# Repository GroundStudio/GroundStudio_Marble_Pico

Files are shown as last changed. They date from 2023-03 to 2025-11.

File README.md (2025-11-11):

GroundStudio Marble Pico
====================================
Marble Pico REV0 0 3

Get it from:

[digikey.com](https://www.digikey.com/en/products/detail/groundstudio/RLJDMV-AAA/21080805)

[ardushop.ro](https://ardushop.ro/en/groundstudio/1590-marble-pico-6427854000682.html)

Explore all the GroundStudio products at [ardushop.ro](https://ardushop.ro/en/37-groundstudio)

Description
-------------------
RP2040 based development board with 26 GPIO, 16 controllable PWM channels, three 12-bit ADC with dedicated ADC voltage reference, 8MB external SPI Flash memory, I²C 3V3 adapter and microSD card adapter.

Contents
-------------------

* [/Documentation](https://github.com/GroundStudio/GroundStudio_Marble_Pico/tree/main/Documentation) -- Contains documentation written during creation of this repository, with readme.md index of its own!
* [/Firmware](https://github.com/GroundStudio/GroundStudio_Marble_Pico/tree/main/Firmware) -- Firmware (bootloaders, etc)
* [/Hardware](https://github.com/GroundStudio/GroundStudio_Marble_Pico/tree/main/Hardware) -- Schematics, layout.
* [/Libraries](https://github.com/GroundStudio/GroundStudio_Marble_Pico/tree/main/Libraries) -- Arduino/CircuitPython libraries. 

Versions
-------------------
*(Not all tags shown)*
* [V0.0.3] Initial release version

License
-------------------
This is released under the [Attribution-ShareAlike 4.0 International (CC BY-SA 4.0)](https://creativecommons.org/licenses/by-sa/4.0/) license. 
**You are welcome to use this for commercial purposes.**

Please consider contributing back to this project or others to help the open-source hardware community continue to thrive and grow! 

Certifications:   
[Open Source Hardware Association](https://certification.oshwa.org/ro000001.html)  
   
certification-mark-RO000001-wide (https://certification.oshwa.org/ro000001.html)

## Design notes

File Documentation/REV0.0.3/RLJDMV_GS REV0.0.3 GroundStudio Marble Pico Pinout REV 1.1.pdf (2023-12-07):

# GroundStudio Marble Pico

RP2040 based development board with 25 GPIO, 16 controllable PWM channels, three 12-bit ADC with dedicated ADC voltage reference, 8MB external SPI Flash memory, I²C 3V3 adapter and microSD card adapter

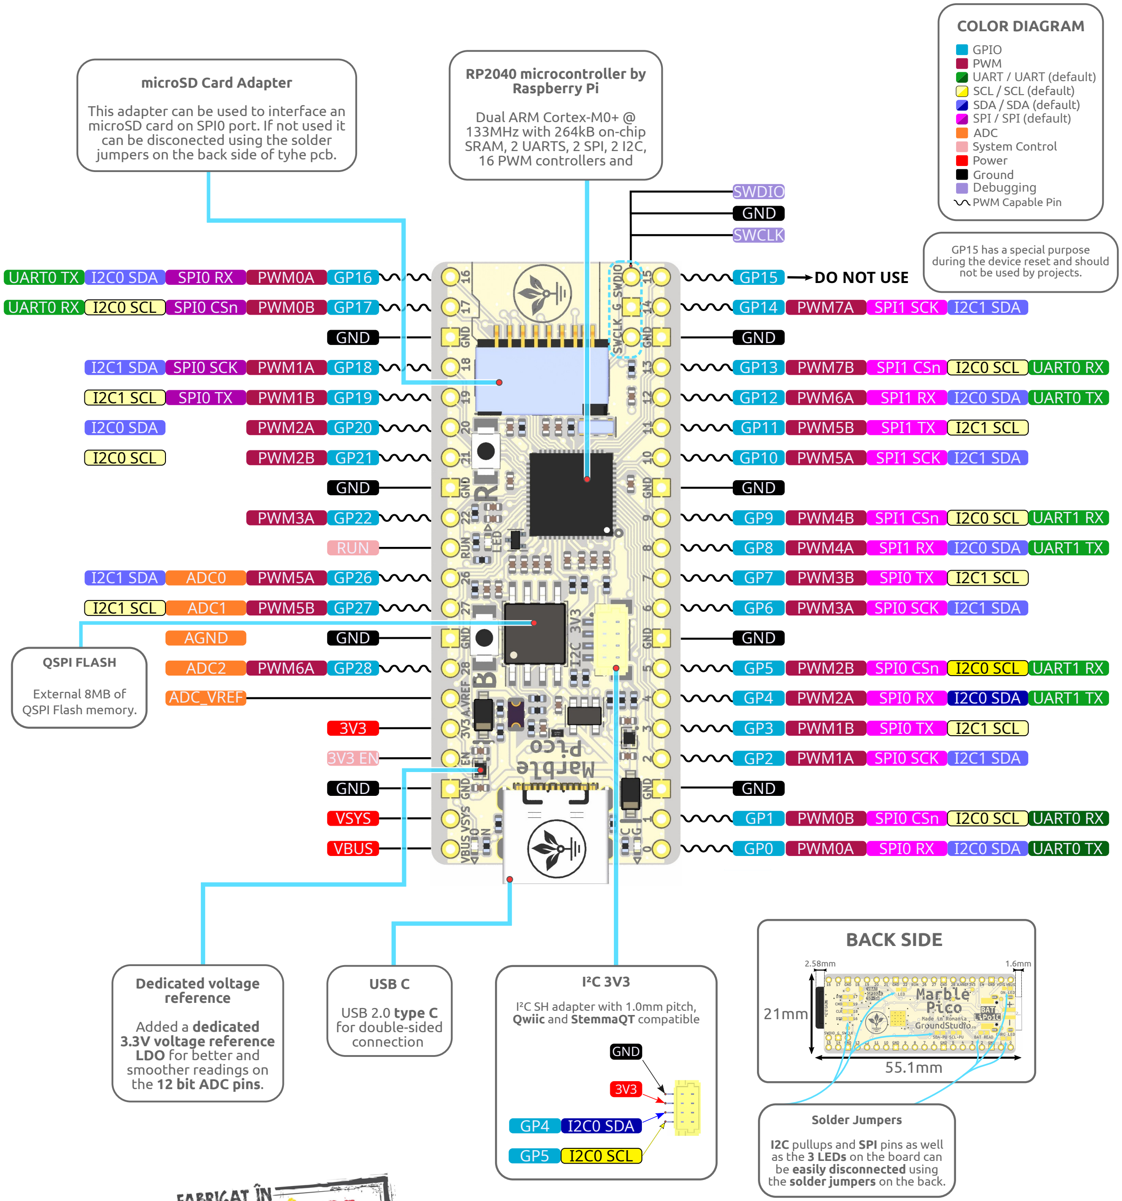
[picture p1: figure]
ADC_VREF; AGND ADC2; ADC0 ADC1; SPI0 RX PWM0A SPI0 CSn; SPI0 SCK SPI0 TX; I2C0 SDA I2C0 SCL; I2C1 SDA I2C1 SCL I2C0 SDA I2C0 SCL; I2C1 SDA I2C1 SCL; UART0 RX; UART0 TX; PWM0B; PWM1A PWM1B PWM2A PWM2B; PWM7B PWM6A PWM5B PWM5A; PWM4B PWM4A PWM3B PWM3A; PWM2B PWM2A PWM1B PWM1A; PWM3A; PWM5A PWM5B; PWM6A; PWM7A; PWM0B PWM0A; GND; RUN; SWCLK; SWDIO; VBUS; VSYS; UART0 RX UART0 TX; UART1 RX UART1 TX; SPI1 RX; SPI0 CSn; SPI0 SCK; SPI0 TX; SPI0 RX; SPI1 CSn; SPI1 SCK; SPI1 TX; I2C0 SDA; I2C0 SCL; I2C1 SDA; I2C1 SCL; RP2040 microcontroller by Raspberry Pi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

This adapter can be used to interface an microSD card on SPI0 port. If not used it

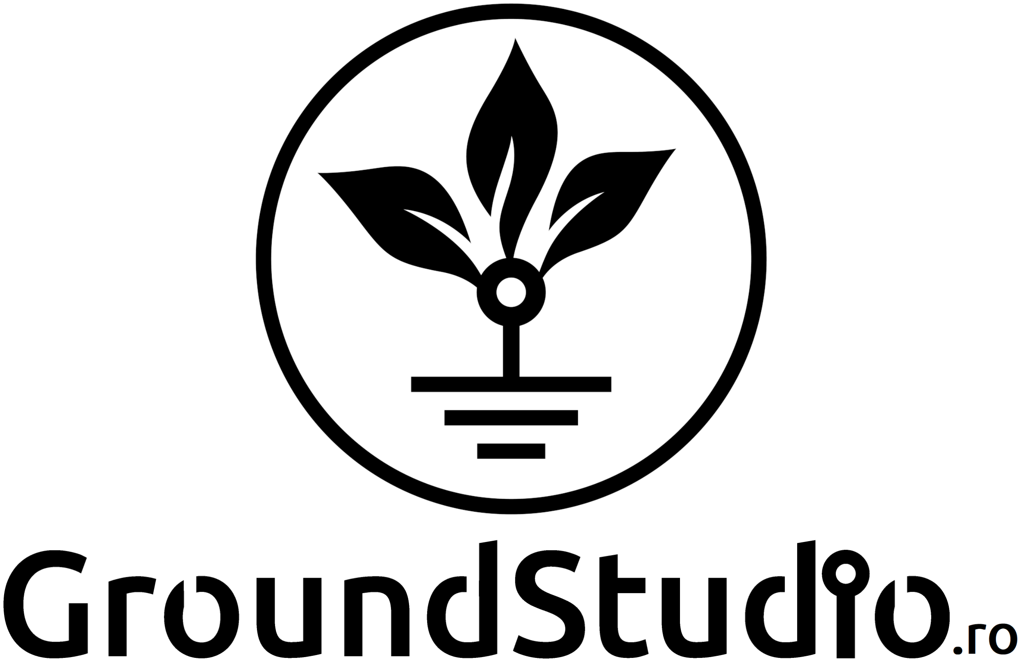
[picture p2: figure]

Board:

Credits:

Copyright:

License:

ARDUSHOP SRL 2023

Attribution-ShareAlike 4.0 International

CC BY-SA 4.0 | Pinout REV: 1.1

"GroundStudio Marble Pico" RLJDMV_GS REV0.0.3

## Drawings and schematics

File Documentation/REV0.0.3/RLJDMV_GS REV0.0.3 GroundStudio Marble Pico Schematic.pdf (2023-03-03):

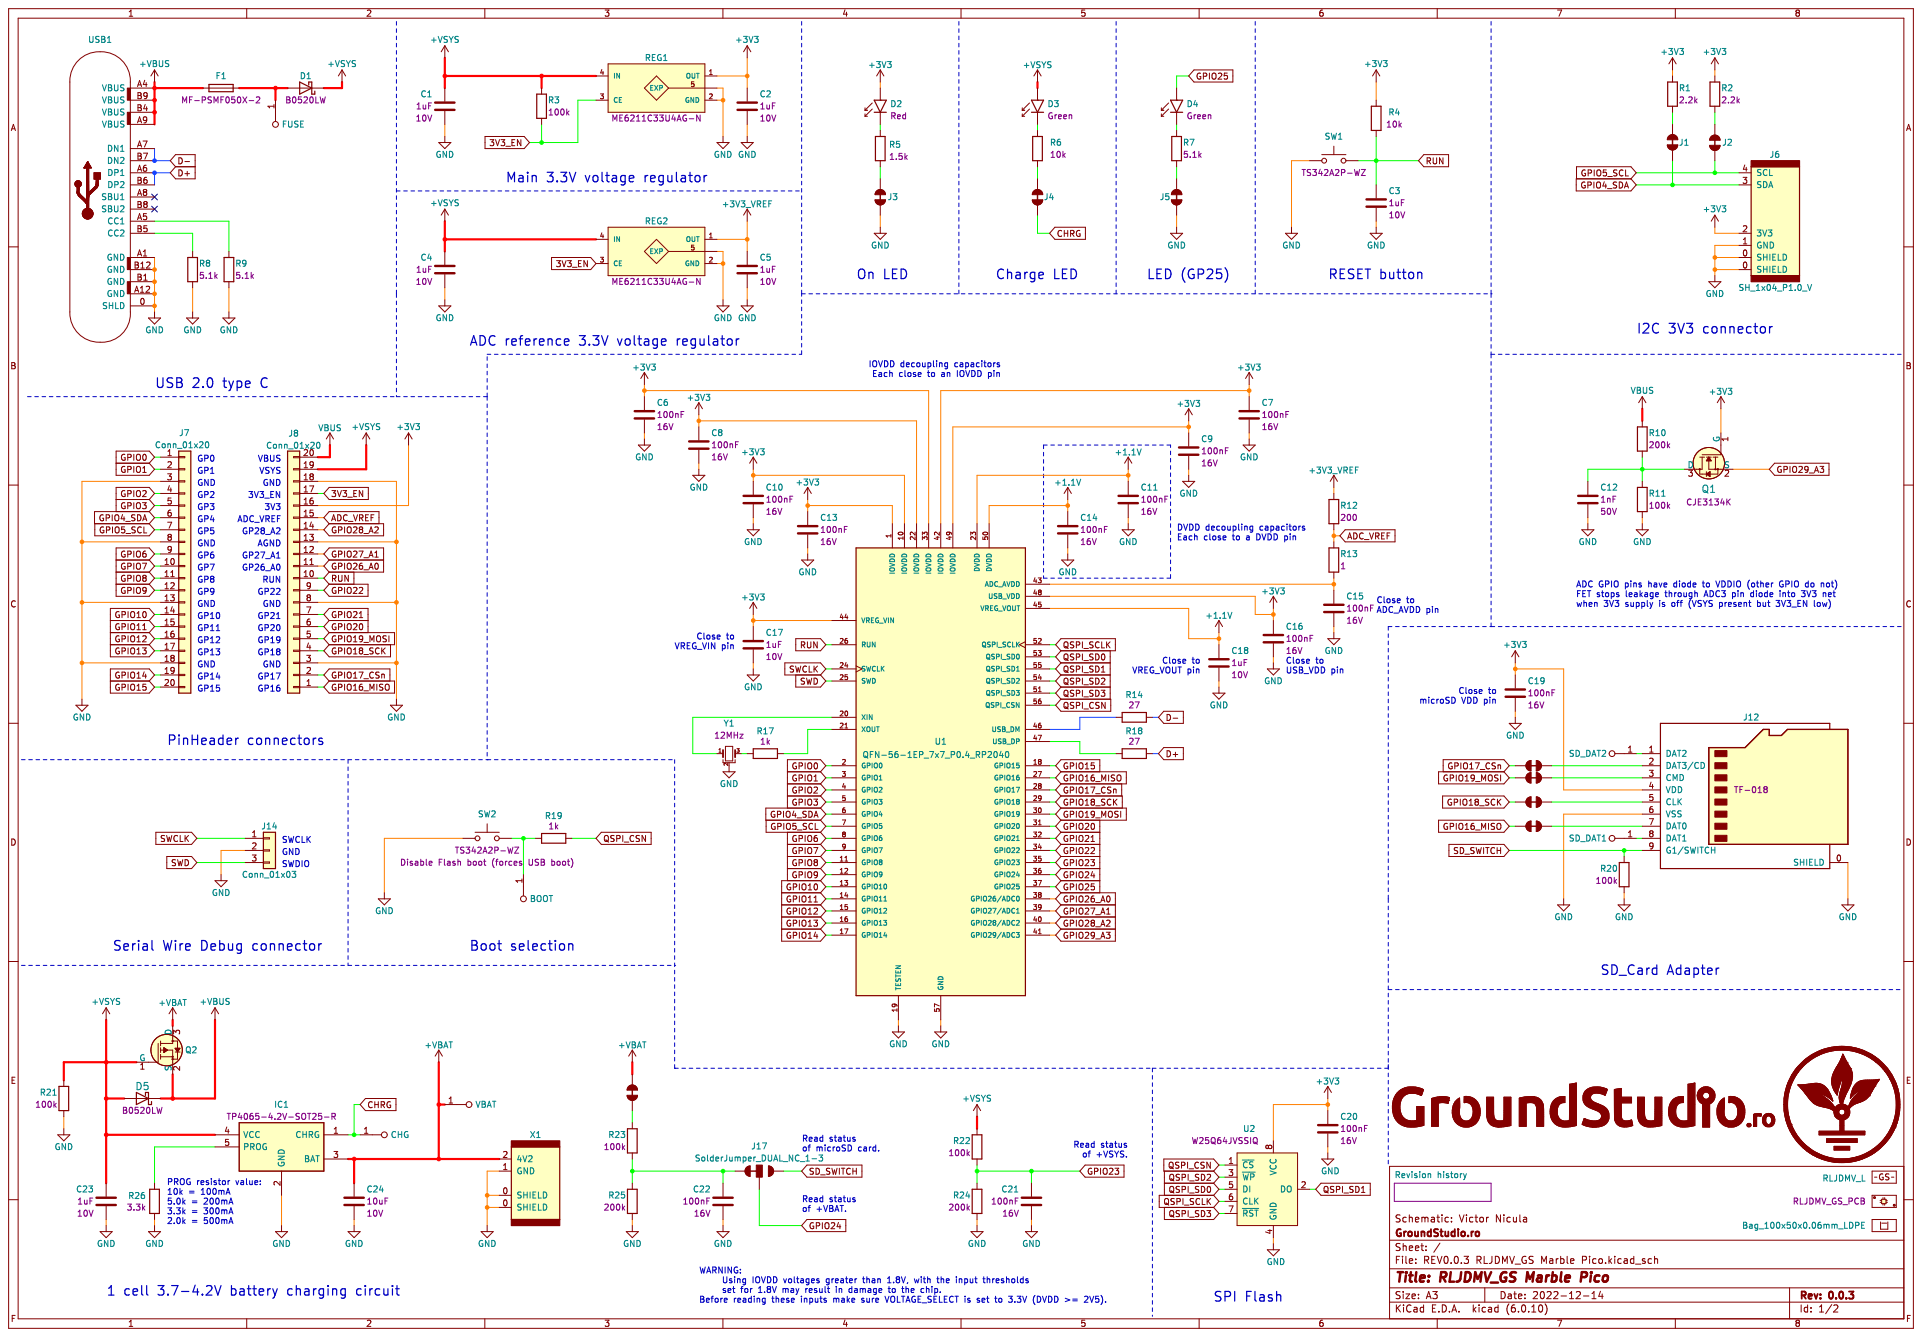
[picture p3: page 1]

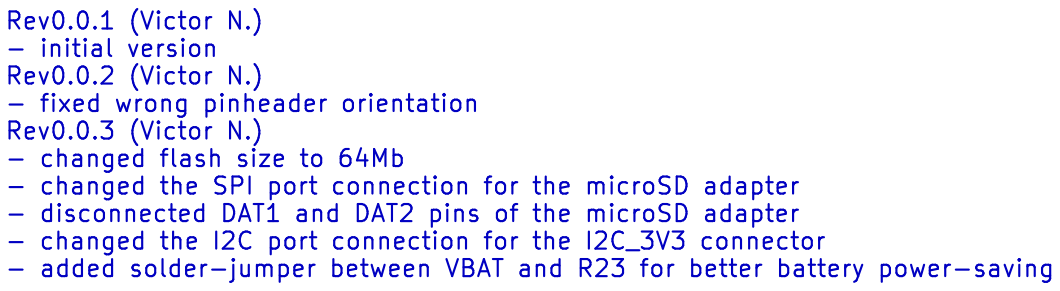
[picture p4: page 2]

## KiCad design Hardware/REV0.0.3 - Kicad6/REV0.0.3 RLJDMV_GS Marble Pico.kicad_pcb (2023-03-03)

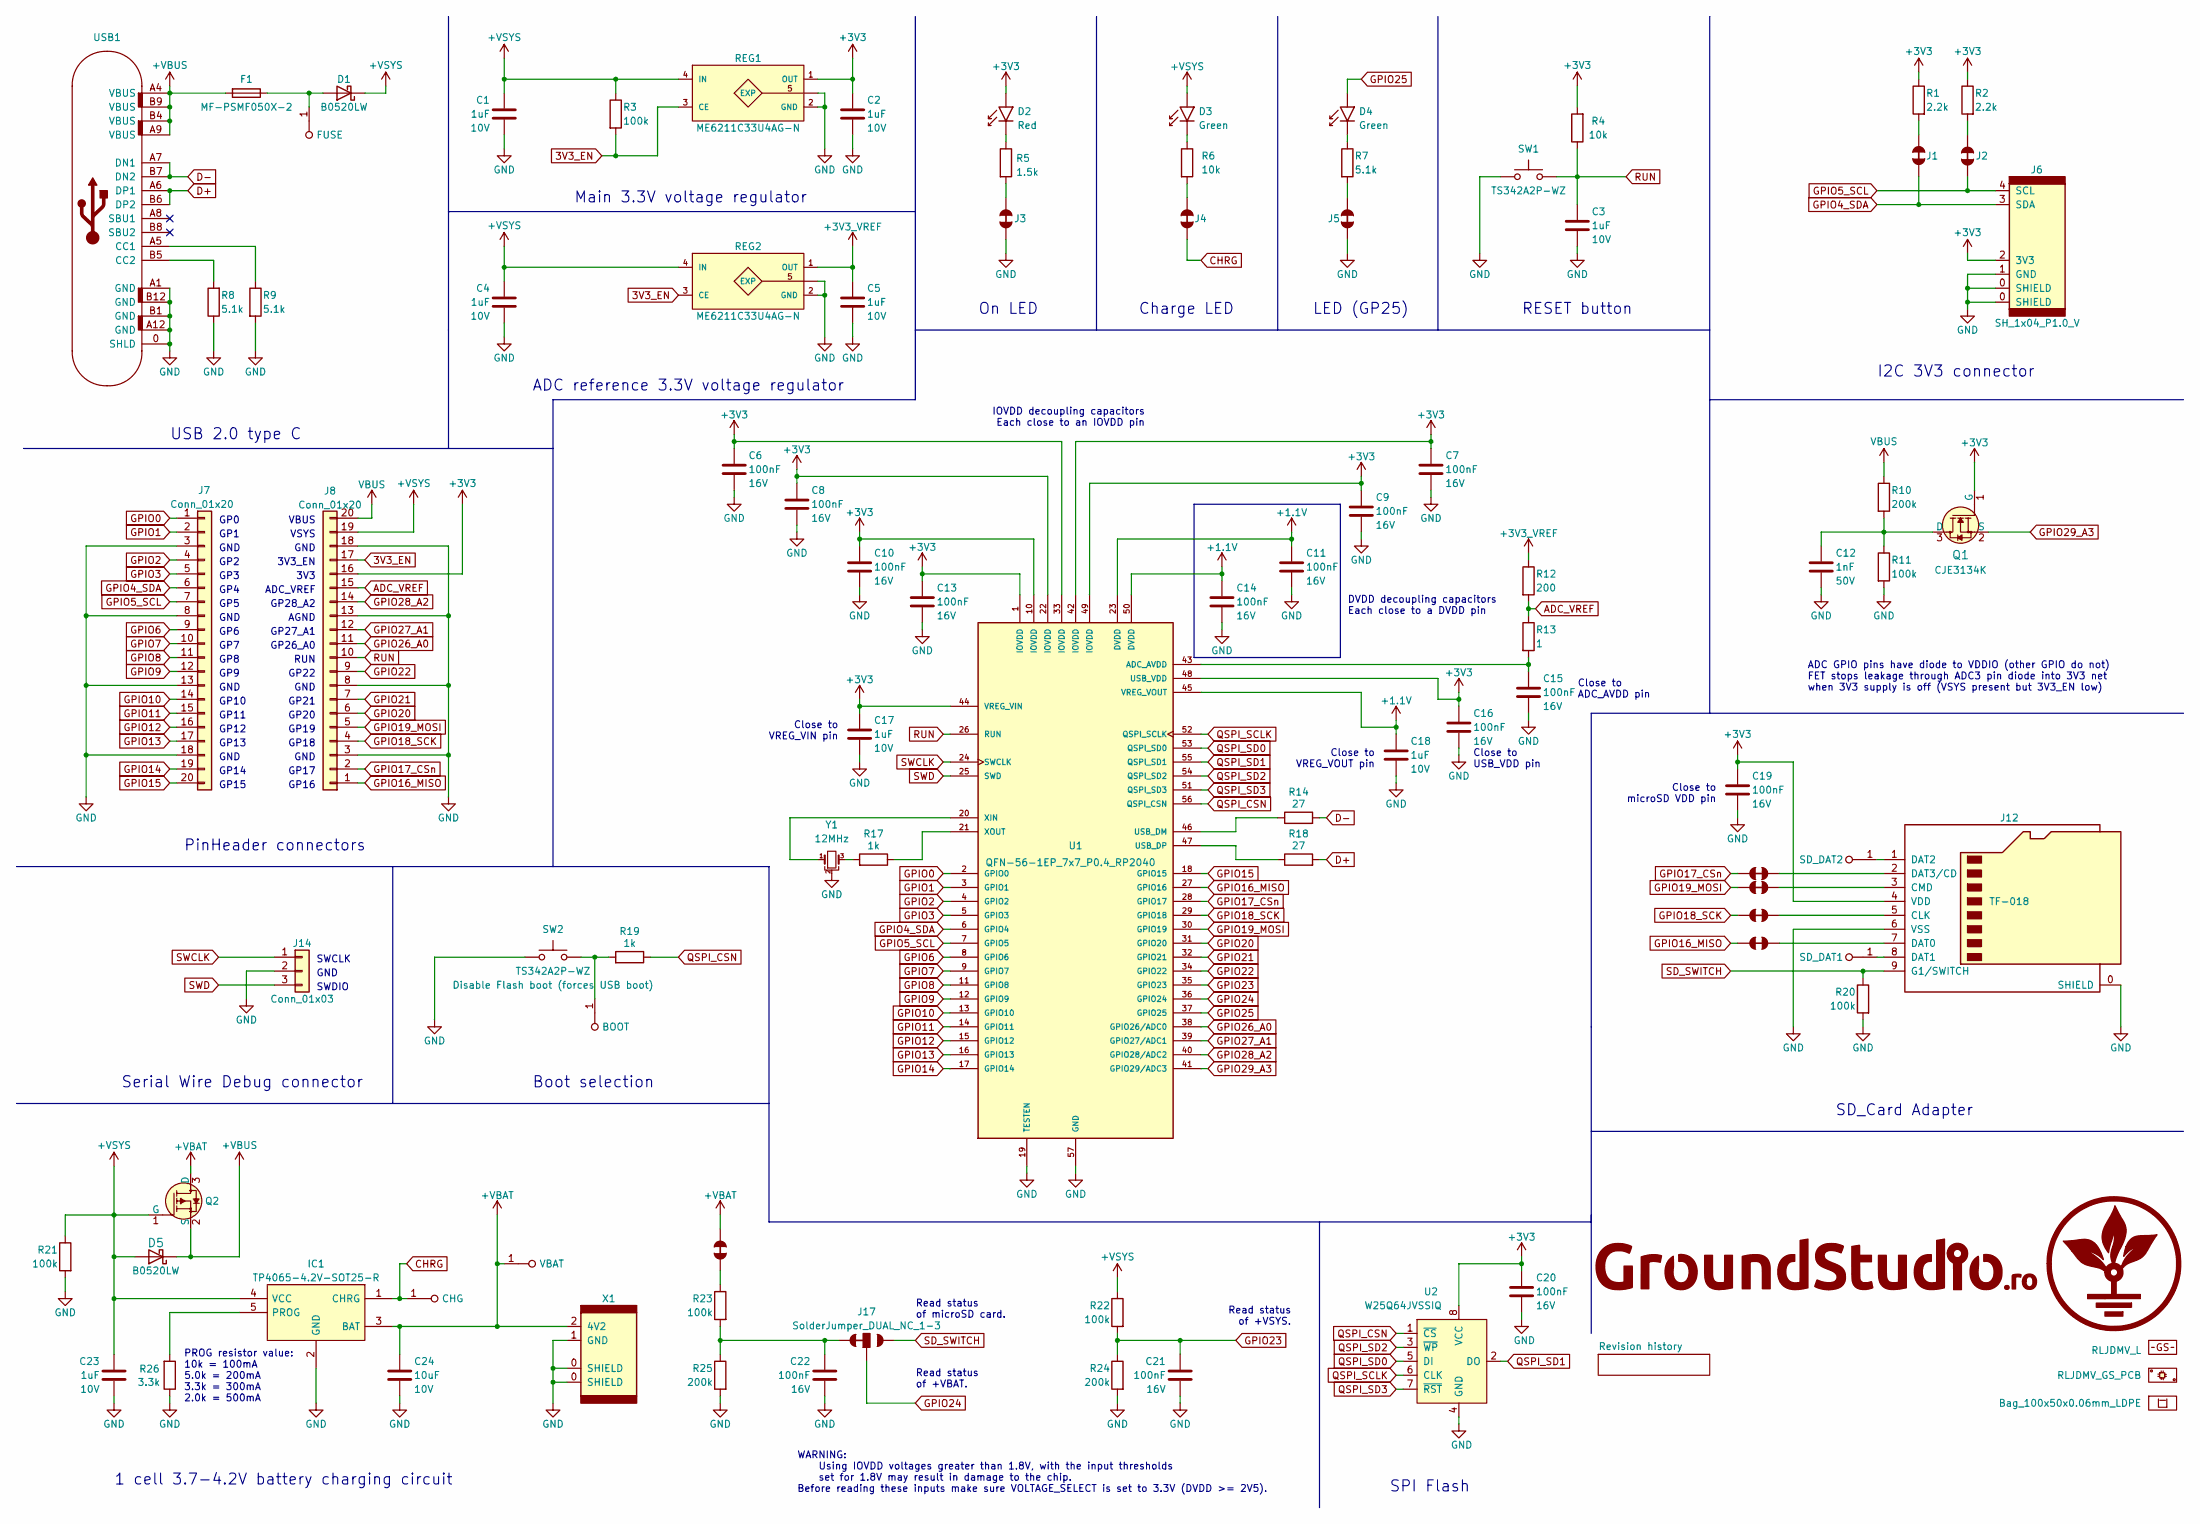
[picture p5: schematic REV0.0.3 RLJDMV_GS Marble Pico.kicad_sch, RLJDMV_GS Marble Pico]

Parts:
B1: Bag_100x50x0.06mm_LDPE; MPN KFHHEG_B
C1, C2, C3, C4, C5, C17, C18, C23: C_0402_1uF_10V; C_0402_alt; Rated voltage 10V; MPN FS15B105K100PKG; LCSC C525324
C6, C7, C8, C9, C10, C11, C13, C14, C15, C16, C19, C20, C21, C22: C_0402_100nF_16V; C_0402_alt; Rated voltage 16V; MPN 0402B104K160CT; LCSC C83056
C12: C_0402_1nF_50V; C_0402_alt; Rated voltage 50V; MPN CC0402KRX7R9BB102; LCSC C106205
C24: C_0402_10uF_10V; C_0402_alt; Rated voltage 10V; MPN LDK105CBJ106MVLF; LCSC C386033
D1, D5: SOD-123_B0520LW; SOD-123; MPN B0520LW; LCSC C89640
D2: LED_0402_RED; LED_0402_alt; MPN TZ-P2-0402RTIA1-0.45T; LCSC C779449
D3, D4: LED_0402_GREEN; LED_0402_alt; MPN TZ-P2-0402GTIA1-0.45T; LCSC C688877
F1: Fuse_0805_MF-PSMF050X-2; Fuse_0805; MPN MF-PSMF050X-2; LCSC C116170
IC1: SOT23-5_TP4065-4.2V; SOT-23-5; MPN TP4065-4.2V-SOT25-R; LCSC C113540
J1, J2, J3, J4, J5, J10, J11, J13, J15: SolderJumper_NC
J6: SH_1x04_P1.0_V; SH__1x04_P1.00mm_Vertical; MPN C145961; LCSC C145961
J7, J8: Conn_01x20; PinHeader_1x20_P2.54mm_Vertical_Male; MPN B-2100S20P-A110; LCSC C124374
J12: TF-018_microSD; TF-018; MPN TF-018; LCSC C961679
J14: Conn_01x03; PinHeader_1x03_P2.54mm_Vertical_Male; MPN C49257; LCSC C49257
J17: SolderJumper_DUAL_NC_1-3
J100: SolderJumper_NC; SolderJumper_NC_Default
L1: RLJDMV_L; MPN RLJDMV_L
P1: PCB; MPN RLJDMV_GS_PCB
Q1: SOT-523_CJE3134K; SOT-523; MPN CJE3134K; LCSC C504104
Q2: SOT-883 LP0404N3T5G; SOT-883; MPN LP0404N3T5G; LCSC C172433
R1, R2: R_0402_2.2k; R_0402_alt; MPN RC-02W2201FT; LCSC C258093
R3, R11, R20, R21, R22, R23: R_0402_100k; R_0402_alt; MPN 0402WGF1003TCE; LCSC C25741
R4, R6: R_0402_10k; R_0402_alt; MPN 0402WGJ0103TCE; LCSC C25531
R5: R_0402_1.5k; R_0402_alt; MPN 0402WGF1501TCE; LCSC C25867
R7, R8, R9: R_0402_5.1k; R_0402_alt; MPN RC-02W5101FT; LCSC C294638
R10, R24, R25: R_0402_200k; R_0402_alt; MPN 0402WGF2003TCE; LCSC C25764
R12: R_0402_200; R_0402_alt; MPN HPCR0402F200RK9; LCSC C364967
R13: R_0402_1; R_0402_alt; MPN RC-02U1R00FT; LCSC C140193
R14, R18: R_0402_27; R_0402_alt; MPN 0402WGF270JTCE; LCSC C25100
R17, R19: R_0402_1k; R_0402_alt; MPN RC-02W1001FT; LCSC C226166
R26: R_0402_3.3k; R_0402_alt; MPN RC-02W3301FT; LCSC C310224
REG1, REG2: FBP1-1-4_ME6211C33U4AG-N; FBP1-1-4; MPN ME6211C33U4AG-N; LCSC C428904
SW1, SW2: TS342A2P-WZ; MPN TS342A2P-WZ; LCSC C557591
TP1: FUSE; TestPoint
TP2: BOOT; TestPoint
TP3: CHG; TestPoint
TP4: VBAT; TestPoint
TP100: SD_DAT2; TestPoint
TP101: SD_DAT1; TestPoint
U1: QFN-56-1EP_7x7_P0.4_RP2040; QFN-56-1EP_7x7mm_P0.4mm_EP4x4mm; MPN RP2040; LCSC C2040
U2: SOIC-8_5.275x5.275_W25Q64JV; SOIC-8_5.275x5.275mm_P1.27mm; MPN W25Q64JVSSIQ; LCSC C83140
USB1: USB_C_FULL; USB_C_C167321; MPN 918-418K2023S40001; LCSC C167321
X1: PH__1x02_P2.0_H; PH__1x02_P2.00mm_Horizontal; MPN C47647; LCSC C47647
Y1: RSN_3P_3.2x1.3_CSTNE12; Rsn_muRata_CSTxE-3Pin_3.2x1.3mm; MPN CSTNE12M0G550000R0; LCSC C341520

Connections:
3V3_EN: J8.17, R3.2, REG1.3 (CE), REG2.3 (CE)
+1.1V: C11.1, C14.1, C18.1, U1.23 (DVDD), U1.45 (VREG_VOUT), U1.50 (DVDD)
+3V3: C2.1, C6.1, C7.1, C8.1, C9.1, C10.1, C13.1, C16.1, C17.1, C19.1, C20.1, D2.2 (A), J6.2 (3V3), J8.16, J12.4 (VDD), Q1.1 (G), R1.1, R2.1, R4.2, REG1.1 (OUT), U1.1 (IOVDD), U1.10 (IOVDD), U1.22 (IOVDD), U1.33 (IOVDD), U1.42 (IOVDD), U1.44 (VREG_VIN), U1.48 (USB_VDD), U1.49 (IOVDD), U2.8 (VCC)
+3V3_VREF: C5.1, R12.1, REG2.1 (OUT)
+VBAT: C24.1, IC1.3 (BAT), J100.2, Q2.3 (D), TP4.1, X1.2 (4V2)
+VSYS: C1.2, C4.2, C23.1, D1.1 (K), D3.2 (A), D5.2 (A), IC1.4 (VCC), J8.19, Q2.1 (G), R3.1, R21.1, R22.1, REG1.4 (IN), REG2.4 (IN)
ADC_VREF: J8.15, R12.2, R13.1
CHRG: IC1.1 (CHRG), J4.1, TP3.1
D+: R18.2, USB1.A6 (DP1), USB1.B6 (DP2)
D-: R14.2, USB1.A7 (DN1), USB1.B7 (DN2)
GND: C1.1, C2.2, C3.2, C4.1, C5.2, C6.2, C7.2, C8.2, C9.2, C10.2, C11.2, C12.2, C13.2, C14.2, C15.2, C16.2, C17.2, C18.2, C19.2, C20.2, C21.2, C22.2, C23.2, C24.2, IC1.2 (GND), J3.1, J5.1, J6.0 (SHIELD), J6.1 (GND), J7.3, J7.8, J7.13, J7.18, J8.3, J8.8, J8.13, J8.18, J12.0 (SHIELD), J12.6 (VSS), J14.2, R8.1, R9.2, R11.2, R20.2, R21.2, R24.2, R25.2, R26.1, REG1.2 (GND), REG1.5 (EXP), REG2.2 (GND), REG2.5 (EXP), SW1.1, SW2.1, U1.19 (TESTEN), U1.57 (GND), U2.4 (GND), USB1.0 (SHLD), USB1.A1 (GND), USB1.A12 (GND), USB1.B1 (GND), USB1.B12 (GND), X1.0 (SHIELD), X1.1 (GND), Y1.2
GPIO0: J7.1, U1.2 (GPIO0)
GPIO1: J7.2, U1.3 (GPIO1)
GPIO2: J7.4, U1.4 (GPIO2)
GPIO3: J7.5, U1.5 (GPIO3)
GPIO4_SDA: J1.2, J6.3 (SDA), J7.6, U1.6 (GPIO4)
GPIO5_SCL: J2.1, J6.4 (SCL), J7.7, U1.7 (GPIO5)
GPIO6: J7.9, U1.8 (GPIO6)
GPIO7: J7.10, U1.9 (GPIO7)
GPIO8: J7.11, U1.11 (GPIO8)
GPIO9: J7.12, U1.12 (GPIO9)
GPIO10: J7.14, U1.13 (GPIO10)
GPIO11: J7.15, U1.14 (GPIO11)
GPIO12: J7.16, U1.15 (GPIO12)
GPIO13: J7.17, U1.16 (GPIO13)
GPIO14: J7.19, U1.17 (GPIO14)
GPIO15: J7.20, U1.18 (GPIO15)
GPIO16_MISO: J8.1, J15.2, U1.27 (GPIO16)
GPIO17_CSn: J8.2, J10.2, U1.28 (GPIO17)
GPIO18_SCK: J8.4, J13.2, U1.29 (GPIO18)
GPIO19_MOSI: J8.5, J11.2, U1.30 (GPIO19)
GPIO20: J8.6, U1.31 (GPIO20)
GPIO21: J8.7, U1.32 (GPIO21)
GPIO22: J8.9, U1.34 (GPIO22)
GPIO23: C21.1, R22.2, R24.1, U1.35 (GPIO23)
GPIO24: J17.3, U1.36 (GPIO24)
GPIO25: D4.2 (A), U1.37 (GPIO25)
GPIO26_A0: J8.11, U1.38 (GPIO26/ADC0)
GPIO27_A1: J8.12, U1.39 (GPIO27/ADC1)
GPIO28_A2: J8.14, U1.40 (GPIO28/ADC2)
GPIO29_A3: Q1.2 (S), U1.41 (GPIO29/ADC3)
unnamed: C12.1, Q1.3 (D), R10.2, R11.1
unnamed: C15.1, R13.2, U1.43 (ADC_AVDD)
unnamed: C22.1, J17.1, R23.2, R25.1
unnamed: D1.2 (A), F1.1, TP1.1
unnamed: D2.1 (K), R5.1
unnamed: D3.1 (K), R6.1
unnamed: D4.1 (K), R7.1
unnamed: IC1.5 (PROG), R26.2
unnamed: J1.1, R1.2
unnamed: J2.2, R2.2
unnamed: J3.2, R5.2
unnamed: J4.2, R6.2
unnamed: J5.2, R7.2
unnamed: J10.1, J12.2 (DAT3/CD)
unnamed: J11.1, J12.3 (CMD)
unnamed: J12.1 (DAT2), TP100.1
unnamed: J12.5 (CLK), J13.1
unnamed: J12.7 (DAT0), J15.1
unnamed: J12.8 (DAT1), TP101.1
unnamed: J100.1, R23.1
unnamed: R8.2, USB1.B5 (CC2)
unnamed: R9.1, USB1.A5 (CC1)
unnamed: R14.1, U1.46 (USB_DM)
unnamed: R17.1, U1.21 (XOUT)
unnamed: R17.2, Y1.3
unnamed: R18.1, U1.47 (USB_DP)
unnamed: R19.2, SW2.2, TP2.1
unnamed: U1.20 (XIN), Y1.1
QSPI_CSN: R19.1, U1.56 (QSPI_CSN), U2.1 (~CS)
QSPI_SCLK: U1.52 (QSPI_SCLK), U2.6 (CLK)
QSPI_SD0: U1.53 (QSPI_SD0), U2.5 (DI)
QSPI_SD1: U1.55 (QSPI_SD1), U2.2 (DO)
QSPI_SD2: U1.54 (QSPI_SD2), U2.3 (~WP)
QSPI_SD3: U1.51 (QSPI_SD3), U2.7 (~RST)
RUN: C3.1, J8.10, R4.1, SW1.2, U1.26 (RUN)
SD_SWITCH: J12.9 (G1/SWITCH), J17.2, R20.1
SWCLK: J14.1, U1.24 (SWCLK)
SWD: J14.3, U1.25 (SWD)

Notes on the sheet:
Main 3.3V voltage regulator
GND
USB 2.0 type C
Boot selection
GP17
GP20
GP2
GP18
RESET button
Read status of microSD card.
GP15
VSYS
GP11
GP10
GP8
Charge LED
GP3
GP9
GP22
Close to USB_VDD pin
Serial Wire Debug connector
SWDIO
SWCLK
RUN
GP7
Close to microSD VDD pin
GP19
SPI Flash
Close to VREG_VOUT pin
GP12
ADC GPIO pins have diode to VDDIO (other GPIO do not) FET stops leakage through ADC3 pin diode into 3V3 net when 3V3 supply is off (VSYS present but 3V3_EN low)
ADC reference 3.3V voltage regulator
GP26_A0
GP14
IOVDD decoupling capacitors Each close to an IOVDD pin
ADC_VREF
GP5
LED (GP25)
On LED
GP0

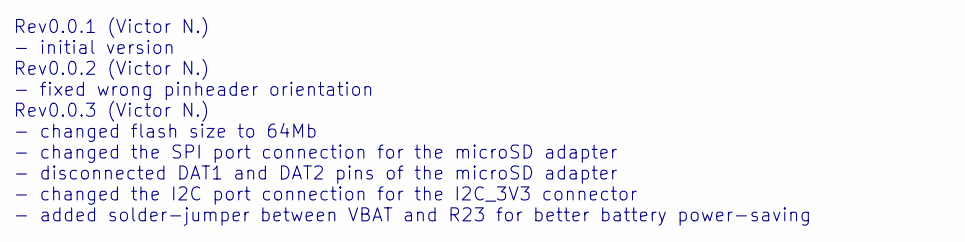
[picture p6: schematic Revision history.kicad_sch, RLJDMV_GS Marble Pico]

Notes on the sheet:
Rev0.0.1 (Victor N.) - initial version Rev0.0.2 (Victor N.) - fixed wrong pinheader orientation Rev0.0.3 (Victor N.) - changed flash size to 64Mb - changed the SPI port connection for the microSD adapter - disconnected DAT1 and DAT2 pins of the microSD adapter - changed the I2C port connection for 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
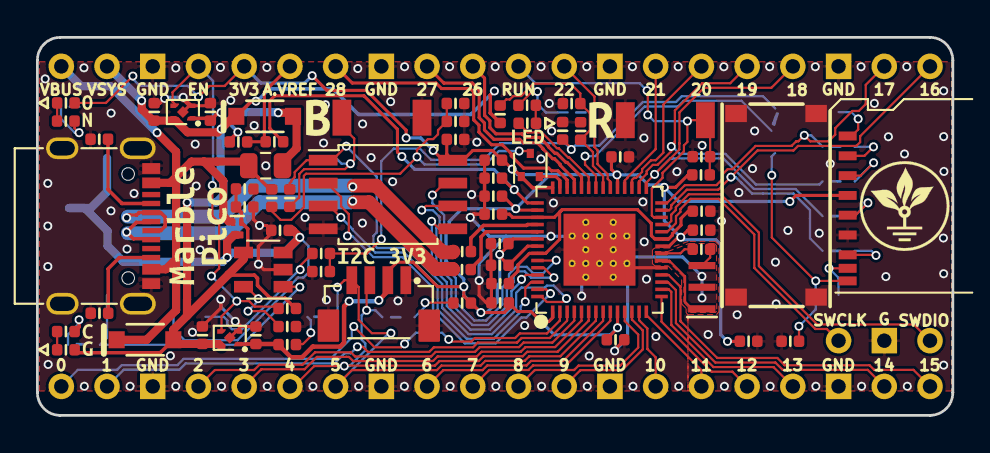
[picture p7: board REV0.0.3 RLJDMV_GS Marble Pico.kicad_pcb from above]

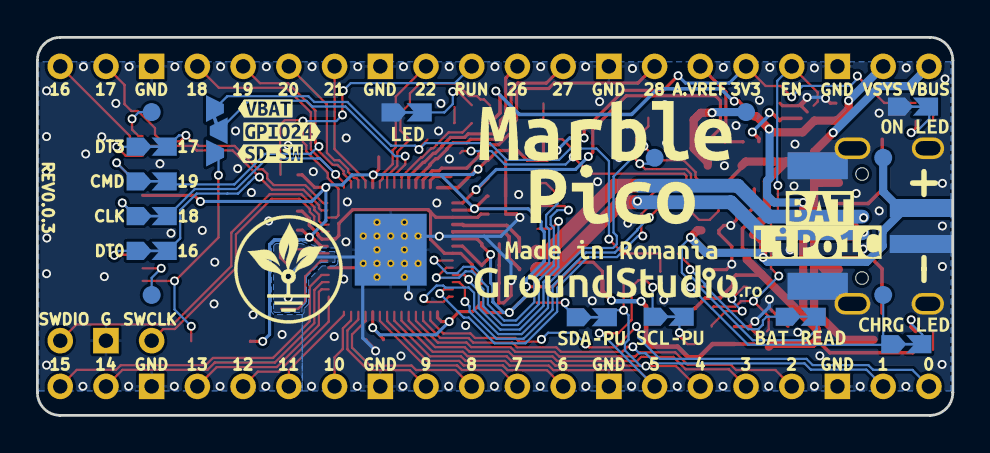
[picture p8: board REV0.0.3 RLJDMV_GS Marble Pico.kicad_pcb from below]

Board: 2 copper layers, 50.9 x 21.0 mm, 112 parts (29 on the bottom side), 80 nets.

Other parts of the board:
kibuzzard-632C0BB6: G***; kibuzzard-632C0BB6
kibuzzard-632C0BC8: G***; kibuzzard-632C0BC8
kibuzzard-639AEA0F: G***; kibuzzard-639AEA0F
kibuzzard-639B16C2: G***; kibuzzard-639B16C2
kibuzzard-63497F21: G***; kibuzzard-63497F21
kibuzzard-634012B7: G***; kibuzzard-634012B7
kibuzzard-634012BF: G***; kibuzzard-634012BF
kibuzzard-634014D4: G***; kibuzzard-634014D4
kibuzzard-634022BB: G***; kibuzzard-634022BB
kibuzzard-634022DD: G***; kibuzzard-634022DD
kibuzzard-6340151A: G***; kibuzzard-6340151A
kibuzzard-6340179C: G***; kibuzzard-6340179C
kibuzzard-6340242C: G***; kibuzzard-6340242C
kibuzzard-6340244C: G***; kibuzzard-6340244C
kibuzzard-6340246F: G***; kibuzzard-6340246F
kibuzzard-6340261C: G***; kibuzzard-6340261C
kibuzzard-63401192: G***; kibuzzard-63401192
kibuzzard-63401212: G***; kibuzzard-63401212
kibuzzard-63401226: G***; kibuzzard-63401226
kibuzzard-63401276: G***; kibuzzard-63401276
kibuzzard-63401294: G***; kibuzzard-63401294
kibuzzard-63402330: G***; kibuzzard-63402330
kibuzzard-63402571: G***; kibuzzard-63402571
kibuzzard-63402583: G***; kibuzzard-63402583

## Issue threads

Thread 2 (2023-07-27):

Add pull-ups resistors on MISO/MOSI of SD-Card

arabine, 2023-07-27:
Hi,

You have made a very wondeful board. However, you should add on a future revision two pull-ups resistors on the MISO/MOSI signals of the SDCARD, 10K each.

Regards.

victor1115, 2023-09-08:
Hello,

Thanks for your feedback.
We've studied the matter more thoroughly and decided to make this adjustment on the next revision.

Best regards.

Closed 2023-09-08.

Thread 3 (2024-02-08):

Powering via USB and VBUS concurrently

CatalinMustata, 2024-02-08:
Hey guys! I'm planning to use the board as a brains for a guitar effects looper and most of the time it will be powered through it's own power supply through the VBUS pin. However, when adjusting presets I foresee a case where I'll have both the USB port connected and the internal supply. Would this be a problem for the device or host?  I'm assuming not, since GND pin would be connected to both supplies, but I thought I'd double check.

victor1115, 2024-02-13:
Hi Catalin,
On the current revision it is NOT possible to supply power via USB and VBUS concurrently.
This issue will be fixed on the next revision of the board.

CatalinMustata, 2024-07-20:
Hey Victor,

Sorry to revive this, but I had to pause my project for a while and I only picked it up again now. I'm trying to figure out the best way to achieve automatic switching between the internal supply and USB power.

The simplest solution I came across was to add a 5V Zener between the internal supply and VBUS - my thinking is that when USB powered VBUS will be roughly a 5V and no current would flow form my internal supply. Do you think this is a good approach? If not, I'm open to any suggestions.

Some other ideas I had were using a PNP transistor with the base connected to VBUS and VSYS connected to its collector _or_ using a logic gate to reading from my internal supply and VBUS (supply & !VBUS) and feeding VSYS.

Closed 2024-02-13.

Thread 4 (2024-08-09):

Marble Pico 2

annonymous12343, 2024-08-09:
Hi GroundStudio! I was curious if you will make a marble pico 2 using the new rp2350. Thanks for making this board! Its my favorite!

FreezeS, 2024-08-18:
Hello!

We very much want to, however the guys from Raspberry Pi never answered our emails.
So we'll have to wait until the chip is available in the regular distribution channels.
For the first version we'll just do a drop-in replacement and then we'll make an improved version.

annonymous12343, 2024-08-18:
Ok, thanks for letting me know! I cant wait for the new version!

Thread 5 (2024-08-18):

Marble Pico connectivity on MacOS

CatalinMustata, 2024-08-18:
Hey guys!

I've got a basic example running on the Marble using the official RPi Pico guide, but I noticed I don't have the expected `/dev/ttyACM0` or any valid serial port (I do get `/dev/tty.Bluetooth-Incoming-Port`, but that's unusable).
Should note I'm running this on a M2 Mac using MacOS Sonoma (14.6.1)

I can program the board through VSCode without issues (Arduino IDE has some issues with the toolchain after the migration to Apple Silicon which I have yet to solve), but I would be great to have Serial communication through USB available as well.

Any suggestions are highly appreciated.

victor1115, 2025-02-18:
Hi Catalin,

Unfortunately, we currently have the possibility to test the functionality only on Windows and Linux systems.

Closed 2025-02-18.

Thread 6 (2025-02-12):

Step file with components

vidarw, 2025-02-12:
Hi,
Could you provide a CAD/Step file with components so we can do physical modeling and take your board into consideration?

victor1115, 2025-02-18:
Hi vidarw,
I've added a step file with the board in the "Hardware/3D Files/" folder.
Here's a link to the file: https://github.com/GroundStudio/GroundStudio_Marble_Pico/tree/main/Hardware/3D%20Files

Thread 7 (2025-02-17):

Documentation - How to reset while battery powered

vidarw, 2025-02-17:
Hi,
Could you elaborate a bit on the battery charging circuitry and how to best utilize it in a safe manner?
How do you for instance boot/flash/restart the Marble Pico while battery powered. Is it possible to make it sleep somehow or do we need to add a physical on/off switch to the battery?

victor1115, 2025-02-18:
Hi vidarw,
The circuit schematic is available here: https://github.com/GroundStudio/GroundStudio_Marble_Pico/blob/main/Documentation/REV0.0.3/RLJDMV_GS%20REV0.0.3%20GroundStudio%20Marble%20Pico%20Schematic.pdf
At the moment we cannot provide any support for specific functionalities or use cases.

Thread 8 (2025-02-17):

Purpose of GPIO15 as I need it

vidarw, 2025-02-17:
Hi,
A bit late to discover when you have the boards and such. But I have PCBs made for the original RP2040 and need GPIO15. What is the downside of using it? Could you please explain a bit further what the pinout stating that used for "reset" mean?

victor1115, 2025-02-18:
Hi vidarw,
The GPIO15 pin has to do with a workaround for an issue mentioned in the datasheet on page 630 "USB device fails to exit RESET state on busy USB bus".
This is a link where you can find the datasheet: https://datasheets.raspberrypi.com/rp2040/rp2040-datasheet.pdf

Closed 2025-02-18.
